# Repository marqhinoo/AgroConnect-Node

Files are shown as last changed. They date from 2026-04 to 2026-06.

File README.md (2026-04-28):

# AgroConnect - Nodo de Monitoreo Agrícola Profesional

AgroConnect es un sistema de monitoreo de precisión diseñado para el agro, basado en el microcontrolador **ESP32-WROOM-32U**. Este nodo está optimizado para recolectar datos críticos del suelo y del ambiente, procesarlos bajo una estrategia de **ultra bajo consumo** (24.5 mAh/día) y transmitirlos mediante **Wi-Fi de alta ganancia o LoRa**.

## 🚀 Características Principales
- **Conectividad Híbrida:** Wi-Fi mediante antena externa de 8dBi y soporte para LoRa (Sx1278).
- **Eficiencia Energética:** Gestión mediante panel solar de 3W, batería 18650 y regulador LDO de baja caída.
- **Monitoreo Ambiental Completo:** Cálculo de VPD utilizando presión atmosférica (BMP280) y sensor de alta precisión SHT30.
- **Análisis de Suelo:** Humedad a dos profundidades (Capacitivos v1.2) y temperatura de raíz (DS18B20).

## 🛠️ Lista de Componentes (Hardware)
| Componente | Función |
| :--- | :--- |
| **ESP32-WROOM-32U** | Microcontrolador central con conector U.FL. |
| **LoRa Sx1278** | Módulo de comunicación de largo alcance (433MHz). |
| **Sensor SHT30** | Humedad y temperatura ambiente (Alta precisión). |
| **Sensor BMP280** | Presión atmosférica y temperatura. |
| **2 x Humedad Suelo v1.2** | Medición capacitiva (anti-corrosión) a 15cm y 40cm. |
| **Sensor DS18B20** | Temperatura de raíz (sumergible). |
| **Panel Solar (6V/3W)** | Generación de energía. |
| **Módulo TP4056 + BMS** | Cargador de batería con protección integrada. |
| **Batería 18650** | Almacenamiento de energía (Litio). |
| **LDO HT7333-A** | Regulador a 3.3V de ultra bajo consumo. |
| **Diodo 1N5817** | Protección anti-retorno para el panel solar. |
| **Capacitor 10µF** | Estabilización de voltaje para picos de transmisión. |

## 📐 Diagrama de Conexión (I2C & SPI)
- **Protocolo I2C (Compartido):** SHT30 y BMP280 conectados a los pines GPIO 21 (SDA) y GPIO 22 (SCL).
- **Protocolo SPI (LoRa):** Conexión del módulo Sx1278 para transmisiones de larga distancia.
- **Entradas Analógicas:** Sensores capacitivos a GPIO 32 y 34.
- **One-Wire:** DS18B20 a GPIO 4 (con resistencia pull-up).

## 📁 Estructura del Repositorio
- `/Firmware`: Código fuente optimizado para Deep Sleep.
- `/Hardware`: Esquemas de conexión y lista de materiales (BOM).
- `/Docs`: Guías de protección (Radomos de PVC) y calibración.

## 📄 Notas de Implementación
Para garantizar que el sensor **SHT30** y el **BMP280** no se mojen, se deben instalar en un protector de radiación solar (Stevenson screen) en la parte exterior del gabinete IP65, asegurando que el cable de la antena de 8dBi esté correctamente sellado con cinta vulcanizada.

---
**AgroConnect** - Optimizando cada gota de agua mediante datos.

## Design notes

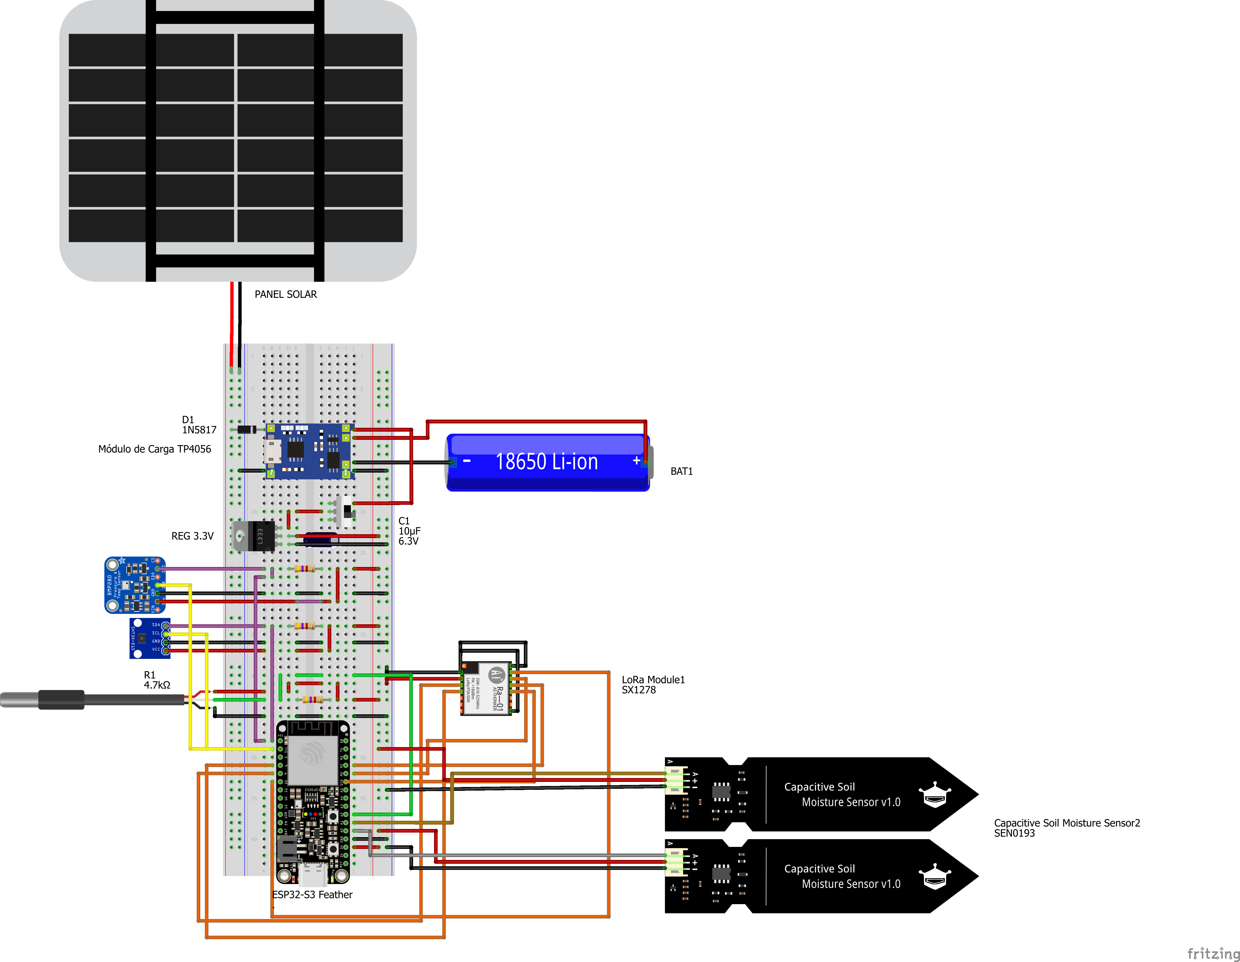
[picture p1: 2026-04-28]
Hardware/Agroconect-Circuit.png

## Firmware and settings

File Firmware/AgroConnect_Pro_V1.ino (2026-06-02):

#include <WiFi.h>
#include <HTTPClient.h>
#include <LoRa.h>
#include <ArduinoJson.h>
#include <Wire.h>
#include <Adafruit_BMP280.h>
#include <Adafruit_SHT31.h>
#include <OneWire.h>
#include <DallasTemperature.h>

// ==========================================
// CONFIGURACIÓN DE ROL E IDENTIFICACIÓN
// ==========================================
const bool ES_MAESTRO_GATEWAY = false;       // Cambiar a TRUE para el de la casa/base, FALSE para el de campo
const char* idNodo = "nodo_campo_01";        // Si es Maestro, el código automáticamente usará "nodo_maestro_base"

// --- Configuración WiFi e IP Estática ---
IPAddress local_IP(192, 168, 1, 150); 
IPAddress gateway(192, 168, 1, 1);
IPAddress subnet(255, 255, 255, 0);

const char* ssid = "TU_WIFI_RURAL";
const char* password = "TU_PASSWORD";
const char* serverName = "https://daily-pusher-sapling.ngrok-free.app/update";

// --- Pines Módulo LoRa ---
#define NSS 10
#define RST 9
#define DIO0 6

// --- Pines Sensores ---
#define SOIL_15CM A0       
#define SOIL_40CM A1       
#define DS18B20_PIN A2     

const int VALOR_SECO = 3000;   
const int VALOR_HUMEDO = 1200; 

OneWire oneWire(DS18B20_PIN);
DallasTemperature sensors(&oneWire);
Adafruit_BMP280 bmp;
Adafruit_SHT31 sht30 = Adafruit_SHT31();

// Tiempos para el Maestro (en milisegundos)
unsigned long ultimoTiempoMedicionMaestro = 0;
const unsigned long INTERVALO_MEDICION_MAESTRO = 600000; // 10 minutos

// Tiempo de sueño para el Esclavo (en microsegundos)
const uint64_t TIEMPO_DORMIR_ESCLAVO_US = 600 * 1000000ULL; 

int leerHumedadEstable(int pin) {
  long suma = 0;
  for(int i = 0; i < 10; i++) { suma += analogRead(pin); delay(20); }
  return (int)(suma / 10);
}

float calcularVPD(float t, float h) {
  if (isnan(t) || isnan(h)) return 0.0;
  float vpsat = 0.61078 * exp((17.27 * t) / (t + 237.3));
  return vpsat * (1.0 - (h / 100.0));
}

// --- FUNCIÓN GENERAL DE LECTURA (La usan ambos nodos) ---
String generarJsonMedicion(const char* idActual, int wifiCon, int loraCon) {
  float t_aire = sht30.readTemperature();
  float h_aire = sht30.readHumidity();
  float pres = bmp.readPressure() / 100.0F;
  float vpdCalculado = calcularVPD(t_aire, h_aire);
  
  sensors.requestTemperatures(); 
  float t_suelo = sensors.getTempCByIndex(0);
  if (t_suelo == -127.0) t_suelo = 0.0;

  int s1_raw = leerHumedadEstable(SOIL_15CM);
  int s2_raw = leerHumedadEstable(SOIL_40CM);
  
  int hum15 = map(s1_raw, VALOR_SECO, VALOR_HUMEDO, 0, 100); 
  int hum40 = map(s2_raw, VALOR_SECO, VALOR_HUMEDO, 0, 100);
  hum15 = constrain(hum15, 0, 100);
  hum40 = constrain(hum40, 0, 100);

  JsonDocument doc;
  doc["usuario"]   = "admin@agro.com";
  doc["idNodo"]    = idActual;
  doc["tempAire"]  = serialized(String(t_aire, 2));
  doc["humAire"]   = serialized(String(h_aire, 2));
  doc["presion"]   = serialized(String(pres, 2));
  doc["vpd"]       = serialized(String(vpdCalculado, 2));
  doc["hum15"]     = hum15;
  doc["hum40"]     = hum40;
  doc["tempSuelo"] = serialized(String(t_suelo, 1));
  doc["bateria"]   = 4.15; 
  doc["wifiCon"]   = wifiCon;
  doc["loraCon"]   = loraCon;

  String output;
  serializeJson(doc, output);
  return output;
}

void setup() {
  setCpuFrequencyMhz(80); 
  Serial.begin(115200);
  delay(500);

  Wire.begin(); 
  Wire.setClock(100000); 
  sensors.begin(); 

  LoRa.setPins(NSS, RST, DIO0);
  if (!LoRa.begin(433E6)) Serial.println("Error LoRa");

  // Inicializar hardware de sensores locales comunes
  if (!bmp.begin(0x76)) Serial.println("Error BMP280");
  if (!sht30.begin(0x44)) Serial.println("Error SHT30");

  if (!ES_MAESTRO_GATEWAY) {
    // ==========================================
    // EJECUCIÓN: NODO DE CAMPO (ESCLAVO)
    // ==========================================
    Serial.printf("\n--- MODO: NODO DE CAMPO [%s] ---\n", idNodo);
    
    // Mide y envía ráfaga LoRa
    String payloadLoRa = generarJsonMedicion(idNodo, 0, 1);
    Serial.println("Transmitiendo reporte hacia el Maestro...");
    LoRa.beginPacket();
    LoRa.print(payloadLoRa);
    LoRa.endPacket();

    // Esperar ventana de SYNC
    Serial.println("Esperando SYNC_OK...");
    unsigned long startEscucha = millis();
    bool sincronizado = false;

    while (millis() - startEscucha < 3000) { 
      int packetSize = LoRa.parsePacket();
      if (packetSize) {
        String msg = "";
        while (LoRa.available()) msg += (char)LoRa.read();
        if (msg == "SYNC_OK") {
          sincronizado = true;
          break;
        }
      }
    }

    WiFi.disconnect(true);
    WiFi.mode(WIFI_OFF);
    LoRa.sleep();

    if (sincronizado) {
      Serial.println("Sincronizado. Deep Sleep 10 min...");
      esp_sleep_enable_timer_wakeup(TIEMPO_DORMIR_ESCLAVO_US);
    } else {
      Serial.println("Fallo SYNC. Reintento en 30 seg...");
      esp_sleep_enable_timer_wakeup(30 * 1000000ULL);
    }
    esp_deep_sleep_start();

  } else {
    // ==========================================
    // EJECUCIÓN: NODO MAESTRO GATEWAY (CASA)
    // ==========================================
    Serial.println("\n--- MODO: MAESTRO GATEWAY ACTIVADO (SIEMPRE DESPIERTO) ---");
    conectarWiFi();
    
    // Realiza una medición local inmediata de sus propios sensores al arrancar
    String localJson = generarJsonMedicion("nodo_maestro_base", 1, 0);
    enviarAlServidorWeb(localJson);
    ultimoTiempoMedicionMaestro = millis();
  }
}

void loop() {
  // El loop solo corre de forma permanente para el MAESTRO GATEWAY
  if (!ES_MAESTRO_GATEWAY) return;

  // --- TAREA 1: Escuchar y puentear datos de los nodos remotos ---
  int packetSize = LoRa.parsePacket();
  if (packetSize) {
    Serial.println("📡 Reporte remoto detectado por LoRa...");
    String cadenaJsonRemoto = "";
    while (LoRa.available()) cadenaJsonRemoto += (char)LoRa.read();

    if (cadenaJsonRemoto.startsWith("{") && cadenaJsonRemoto.endsWith("}")) {
      // Responder ACK inmediato al esclavo para que se duerma rápido
      delay(50); 
      LoRa.beginPacket();
      LoRa.print("SYNC_OK");
      LoRa.endPacket();
      Serial.println("ACK enviado al nodo remoto.");

      // Subir el JSON del esclavo a la API
      enviarAlServidorWeb(cadenaJsonRemoto);
    }
  }

  // --- TAREA 2: Medir sus propios sensores locales cada 10 minutos ---
  unsigned long tiempoActual = millis();
  if (tiempoActual - ultimoTiempoMedicionMaestro >= INTERVALO_MEDICION_MAESTRO) {
    ultimoTiempoMedicionMaestro = tiempoActual;
    Serial.println("\n[Maestro] Tomando lecturas de sensores locales propios...");
    
    String jsonPropio = generarJsonMedicion("nodo_maestro_base", 1, 0);
    enviarAlServidorWeb(jsonPropio);
  }
}

// --- SUBIDA HTTP DEL MAESTRO ---
void conectarWiFi() {
  if (WiFi.status() == WL_CONNECTED) return;
  WiFi.config(local_IP, gateway, subnet);
  WiFi.begin(ssid, password);
  int intentos = 0;
  while (WiFi.status() != WL_CONNECTED && intentos < 15) { delay(500); intentos++; }
}

void enviarAlServidorWeb(String jsonString) {
  conectarWiFi();
  if (WiFi.status() == WL_CONNECTED) {
    HTTPClient http;
    http.begin(serverName);
    http.addHeader("Content-Type", "application/json");
    int responseCode = http.POST(jsonString);
    Serial.printf("API HTTP Response Status: %d\n", responseCode);
    http.end();
  }
}

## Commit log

2026-04-28 Add circuit
2026-04-28 add list-materials
2026-04-28 add Agroconnect-circuit.fzz
    [Agroconect-circuit.fzz]
2026-05-01 server en su carpeta
    [Agroconect-circuit.fzz]
2026-05-05 Estructura completa: Agregado el servidor Node.js al repositorio
2026-05-05 Limpieza: borrado de archivo de historial viejo
2026-05-07 fix circuit
